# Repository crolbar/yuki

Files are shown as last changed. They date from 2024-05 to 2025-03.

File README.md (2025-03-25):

<h1 align="center">YUKI</h1>

<div align="center">
YUKI is a split diodless keyboard with a column stagger layout heavily inspired by <a href="https://github.com/diepala/cantor">cantor</a>.
</div>
<br/><br/>

YUKI
Made with [Keyberon](https://github.com/TeXitoi/keyberon)

<br/>

### Layers
| Layer | Description |
|---|---|
| [layer 0](http://www.keyboard-layout-editor.com/#/gists/67aaf9d778e9b2ddf6e25b263cbe5ed5) | Firmware Dvorak |
| [layer 1](http://www.keyboard-layout-editor.com/#/gists/5f7a4db98ea4d0b959304c4fe80d1d7f) | Numbers & Symbols |
| [layer 2](http://www.keyboard-layout-editor.com/#/gists/3af9d73abaec154f56b99b5a6c55cf5e) | Less used keys & Macros  |
| layer 3 | Mouse movement & buttons |
| layer 4 | Qwerty |

<br/>

### Features

- 44 keys, v0.1 - Cherry MX & v0.2 - Kailh Choc V1 switches
- Uses only 1U keycaps
- TRRS connection is used for communication between the two halves
- 2 USB-C connectors, with a choice from which the keyboard should send keystrokes
- Mouse control
- OLED display (not installed in the v0.2 picture)

<br/>

# Bill of Materials

| Product | Qty | Note |
|---|-----|---|
| YUKI PCB | 2 | [KiCad](https://kicad.org/) project files can be found in `yuki_pcb` directory. I ordered them from [JLCPCB](https://jlcpcb.com). They are reversible so you will use the same pcb for both left and right. |
| STM32F401CCU6 | 2 | Can be found on aliexpress. I have ordered mine from a local vendor. |
| TRRS jacks | 2 | `PJ-320A` |
| TRRS cable | 1 | 3.5mm jack cable, with 3 stripes. |
| Switches | 44  | Cherry MX for v0.1 and Kailh Choc V1 for v0.2. Ordered from [splitkb](https://splitkb.com/collections/switches-and-keycaps/products/kailh-low-profile-choc-switches) |
| Keycaps | 44  | 1U keycaps. Ordered from [splitkb](https://splitkb.com/collections/switches-and-keycaps/products/blank-mbk-choc-low-profile-keycaps). |

# Flashing the firmware

You will need rust installed so:
```
curl --proto '=https' --tlsv1.2 -sSf https://sh.rustup.rs | sh
```

cargo-binutils for stripping unused data from the rust binary and other optimizations:
```
rustup component add llvm-tools
cargo install cargo-binutils
```

dfu-util for flashing:
```
sudo pacman -S dfu-util
```

add the rust target for the MCU:
```
rustup target add thumbv7em-none-eabihf
```

then to compile the firmware:
``` 
cargo objcopy --bin yuki --release -- -O binary yuki.bin
```
for the right board add `--features right`

to flash enter dfu by holding BOOT clicking RESET and releasing BOOT and enter (can be tricky):
```
dfu-util -d 0483:df11 -a 0 --dfuse-address 0x08000000:leave -D yuki.bin"
```

After that to enter dfu just hold button 05 and 33 click reset and release the buttons.

### Nix

if you are on NixOS you could use the devShell:

enter the dev shell:
```
nix develop
```

and use the flash script that can be found in `flash.nix`
```
flash right
```

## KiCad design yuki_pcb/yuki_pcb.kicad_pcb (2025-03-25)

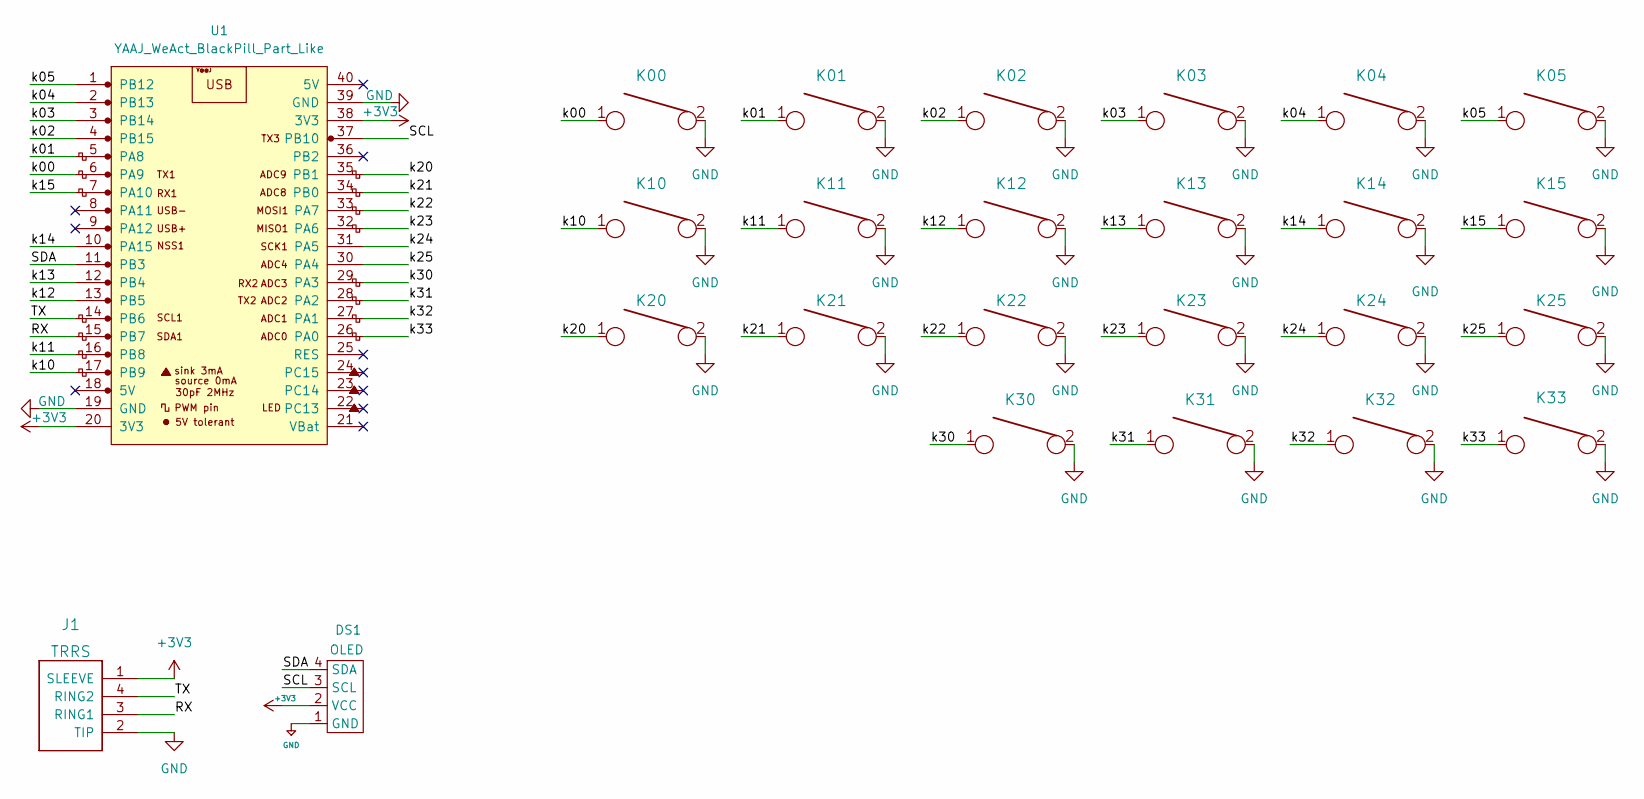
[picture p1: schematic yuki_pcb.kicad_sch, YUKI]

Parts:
DS1: OLED
J1: TRRS; MJ-4PP-9_Cantor_MX_TX-RX_Crossover
K00, K01, K02, K03, K04, K05, K10, K11, K12, K13, K14, K15, K20, K21, K22, K23, K24, K25, K30, K31, K32, K33: KEYSW; Kailh_Choc_PG1350_rev
U1: YAAJ_WeAct_BlackPill_Part_Like; YUKI_YAAJ_WeAct_BlackPill_2

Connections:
+3V3: DS1.2 (VCC), J1.1 (SLEEVE), U1.20 (3V3), U1.38 (3V3)
/RX: J1.3 (RING1), U1.15 (PB7)
/SCL: DS1.3 (SCL), U1.37 (PB10)
/SDA: DS1.4 (SDA), U1.11 (PB3)
/TX: J1.4 (RING2), U1.14 (PB6)
/k00: K00.1, U1.6 (PA9)
/k01: K01.1, U1.5 (PA8)
/k02: K02.1, U1.4 (PB15)
/k03: K03.1, U1.3 (PB14)
/k04: K04.1, U1.2 (PB13)
/k05: K05.1, U1.1 (PB12)
/k10: K10.1, U1.17 (PB9)
/k11: K11.1, U1.16 (PB8)
/k12: K12.1, U1.13 (PB5)
/k13: K13.1, U1.12 (PB4)
/k14: K14.1, U1.10 (PA15)
/k15: K15.1, U1.7 (PA10)
/k20: K20.1, U1.35 (PB1)
/k21: K21.1, U1.34 (PB0)
/k22: K22.1, U1.33 (PA7)
/k23: K23.1, U1.32 (PA6)
/k24: K24.1, U1.31 (PA5)
/k25: K25.1, U1.30 (PA4)
/k30: K30.1, U1.29 (PA3)
/k31: K31.1, U1.28 (PA2)
/k32: K32.1, U1.27 (PA1)
/k33: K33.1, U1.26 (PA0)
GND: DS1.1 (GND), J1.2 (TIP), K00.2, K01.2, K02.2, K03.2, K04.2, K05.2, K10.2, K11.2, K12.2, K13.2, K14.2, K15.2, K20.2, K21.2, K22.2, K23.2, K24.2, K25.2, K30.2, K31.2, K32.2, K33.2, U1.19 (GND), U1.39 (GND)

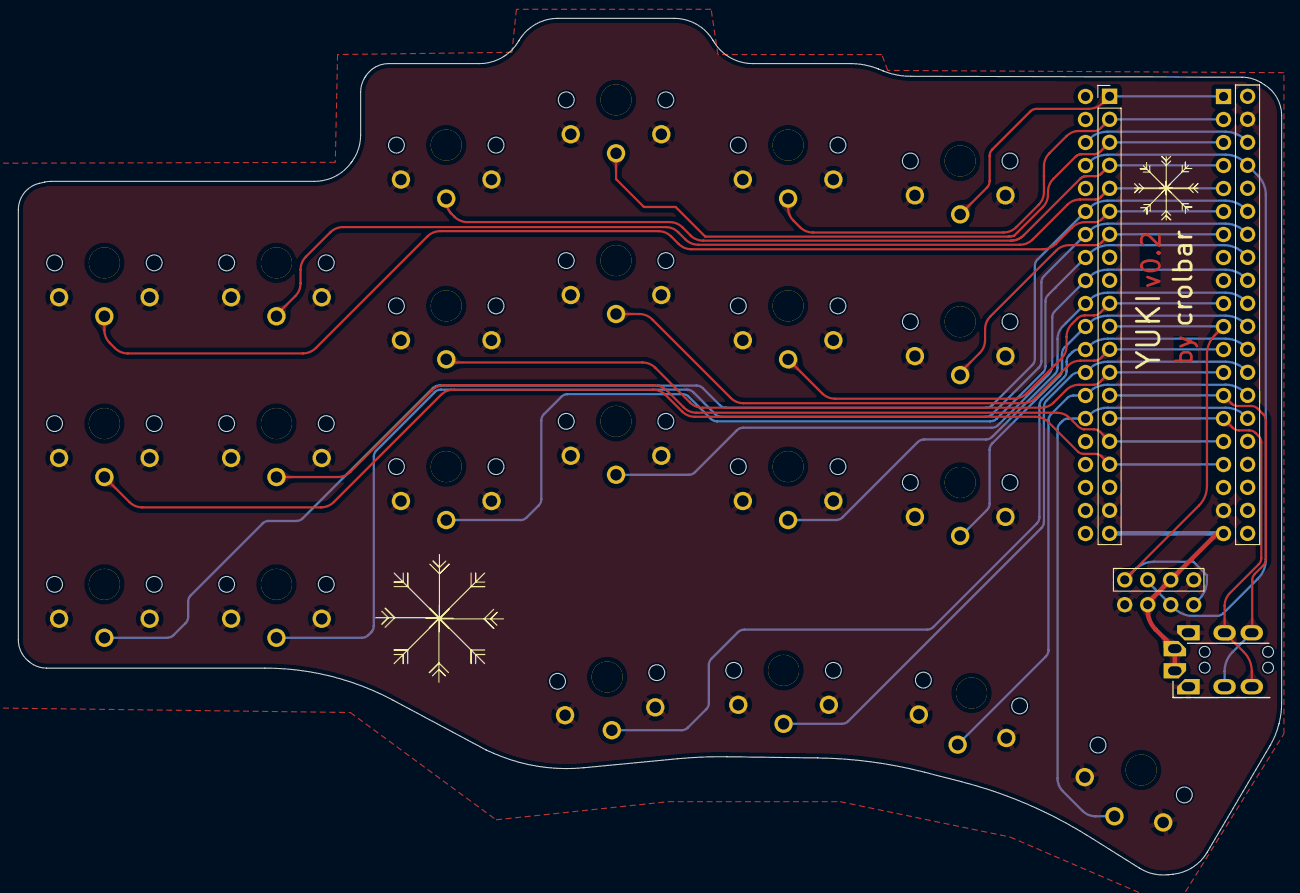
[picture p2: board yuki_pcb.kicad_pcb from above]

Board: 2 copper layers, 139.5 x 94.6 mm, 25 parts (0 on the bottom side), 28 nets.

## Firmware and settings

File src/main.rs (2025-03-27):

#![no_std]
#![no_main]

use panic_halt as _;
use stm32f4xx_hal as hal;
mod layout;
mod oled;
mod mouse;

#[rtic::app(device = hal::pac, dispatchers = [TIM1_CC])]
mod app {
    use {
        super::*,

        hal::{
            gpio::{EPin, Input, PC13, Output, PushPull},
            otg_fs::{UsbBus, UsbBusType, USB},
            pac::{USART1, TIM2},
            timer::counter::CounterHz,
            prelude::*,
            serial
        },
        cortex_m::interrupt,

        nb::block,

        usb_device::prelude::*,

        keyberon::{
            debounce::Debouncer,
            key_code::KbHidReport,
            layout::{Event, Layout, CustomEvent},
            matrix::DirectPinMatrix,
            keyboard
        },

        layout::{LAYERS, CustomAction},
        oled::OLED,
        mouse::Mouse,
    };


    const MANUFACTURER: &str = "crolbar";
    const PRODUCT: &str = "YUKI";
    const SERIAL_NUMBER: &str = "1337";

    const NUM_COLS: usize = 6;
    const NUM_ROWS: usize = 4;

    const NUM_LAYERS: usize = LAYERS.len();

    const USE_RIGHT_USB_INIT: bool = true;


    pub struct Leds { caps_lock:  PC13<Output<PushPull>> }

    impl keyboard::Leds for Leds {
        fn caps_lock(&mut self, status: bool) {
            match status {
                true => self.caps_lock.set_low(),
                false => self.caps_lock.set_high(),
            }
        }
    }

    #[shared]
    struct Shared {
        usb_dev: UsbDevice<'static, UsbBusType>,
        usb_class: keyberon::Class<'static, UsbBusType, Leds>,
        layout: Layout<{NUM_COLS*2}, NUM_ROWS, NUM_LAYERS, CustomAction>,
        mouse: Mouse
    }

    #[local]
    struct Local {
        matrix: DirectPinMatrix<EPin<Input>, NUM_COLS, NUM_ROWS>,
        debouncer: Debouncer<[[bool; NUM_COLS]; NUM_ROWS]>,
        timer: CounterHz<TIM2>,
        tx: serial::Tx<USART1>,
        rx: serial::Rx<USART1>,
        enter_dfu: bool,
        use_right_usb: bool,
        #[cfg(feature = "oled")]
        oled: OLED,
    }


    #[init(
        local = [
            bus: Option<usb_device::bus::UsbBusAllocator<UsbBusType>> = None,
            ep_memory: [u32; 1024] = [0; 1024]
        ]
    )]
    fn init(ctx: init::Context) -> (Shared, Local, init::Monotonics) {
        let mut clocks = ctx
            .device
            .RCC
            .constrain()
            .cfgr
            .use_hse(25.MHz())
            .sysclk(84.MHz())
            .require_pll48clk()
            .freeze();

        let gpioa = ctx.device.GPIOA.split();
        let gpiob = ctx.device.GPIOB.split();
        let gpioc = ctx.device.GPIOC.split();

        // easier dfu enter keys
        let pa0 = gpioa.pa0.into_pull_up_input();
        let pb12 = gpiob.pb12.into_pull_up_input();

        let mut timer = ctx.device.TIM2.counter_hz(&mut clocks);
        timer.start(1.kHz()).unwrap();
        timer.listen(hal::timer::Event::Update);


        let usb = USB::new(
            (
                ctx.device.OTG_FS_GLOBAL,
                ctx.device.OTG_FS_DEVICE,
                ctx.device.OTG_FS_PWRCLK,
            ), 
            (gpioa.pa11, gpioa.pa12), &clocks
        );


        let mut caps_lock = gpioc.pc13.into_push_pull_output();
        caps_lock.set_high();

        *ctx.local.bus = Some(UsbBus::new(usb, ctx.local.ep_memory));
        let usb_bus = ctx.local.bus.as_ref().unwrap();

        let usb_class = keyberon::new_class(usb_bus, Leds {caps_lock});

        let mouse = Mouse::new(usb_bus);

        let usb_dev = UsbDeviceBuilder::new(usb_bus, UsbVidPid(0x16c0, 0x27db))
        .strings(&[StringDescriptors::default()
            .manufacturer(MANUFACTURER)
            .product(PRODUCT)
            .serial_number(SERIAL_NUMBER)])
        .unwrap()
        .build();

        // easier dfu check if keys are pressed
        // do this a bit after setting the pins to high
        let enter_dfu = pa0.is_low() && pb12.is_low();

        let matrix = interrupt::free(move |_| {
            DirectPinMatrix::new([
                [
                    Some(gpioa.pa9.into_pull_up_input().erase()),
                    Some(gpioa.pa8.into_pull_up_input().erase()),
                    Some(gpiob.pb15.into_pull_up_input().erase()),
                    Some(gpiob.pb14.into_pull_up_input().erase()),
                    Some(gpiob.pb13.into_pull_up_input().erase()),
                    Some(pb12.into_pull_up_input().erase()),
                ],
                [
                    Some(gpiob.pb9.into_pull_up_input().erase()),
                    Some(gpiob.pb8.into_pull_up_input().erase()),
                    Some(gpiob.pb5.into_pull_up_input().erase()),
                    Some(gpiob.pb4.into_pull_up_input().erase()),
                    Some(gpioa.pa15.into_pull_up_input().erase()),
                    Some(gpioa.pa10.into_pull_up_input().erase()),
                ],
                [
                    Some(gpiob.pb1.into_pull_up_input().erase()),
                    Some(gpiob.pb0.into_pull_up_input().erase()),
                    Some(gpioa.pa7.into_pull_up_input().erase()),
                    Some(gpioa.pa6.into_pull_up_input().erase()),
                    Some(gpioa.pa5.into_pull_up_input().erase()),
                    Some(gpioa.pa4.into_pull_up_input().erase()),
                ],
                [
                    None,
                    None,
                    Some(gpioa.pa3.into_pull_up_input().erase()),
                    Some(gpioa.pa2.into_pull_up_input().erase()),
                    Some(gpioa.pa1.into_pull_up_input().erase()),
                    Some(pa0.into_pull_up_input().erase()),
                ],
            ]).unwrap()
        });

        let mut serial = serial::Serial::new(
            ctx.device.USART1,
            interrupt::free(move |_| 
                (gpiob.pb6.into_alternate::<7>(), gpiob.pb7.into_alternate::<7>())
            ),
            38_400.bps(),
            &mut clocks
        ).unwrap().with_u8_data();

        serial.listen(serial::Event::RxNotEmpty);
        let (tx, rx) = serial.split();

        (
            Shared {
                usb_dev,
                usb_class,
                layout: Layout::new(&LAYERS),
                mouse,
            },
            Local {
                matrix,
                timer,
                debouncer: Debouncer::new(
                    [[false; NUM_COLS]; NUM_ROWS],
                    [[false; NUM_COLS]; NUM_ROWS],
                    NUM_LAYERS.try_into().unwrap()
                ),
                tx, rx,
                enter_dfu,
                use_right_usb: USE_RIGHT_USB_INIT,
                #[cfg(feature = "oled")]
                oled: OLED::new(
                    gpiob.pb10.into_alternate().set_open_drain(),
                    gpiob.pb3.into_alternate().set_open_drain(),
                    ctx.device.I2C2, &clocks
                )
            },
            init::Monotonics(),
       )
    }

    #[task(priority = 3, capacity = 8, shared = [layout])]
    fn handle_event(mut ctx: handle_event::Context, event: Event) {
        ctx.shared.layout.lock(|l| l.event(event))
    }

    #[task(binds = USART1, priority = 2, local = [rx])]
    fn rx(ctx: rx::Context) {
        if let Ok(b) = ctx.local.rx.read() {
            if let Ok(event) = de(b) {
                #[cfg(not(feature = "right"))]
                let event = event.transform(|i, j| (i, 11 - j));

                handle_event::spawn(event).unwrap();
            }
        }
    }

    #[task(
        binds=TIM2,
        priority=1,
        local=[debouncer, matrix, timer, tx, oled, use_right_usb],
        shared=[usb_dev, usb_class, layout, mouse]
    )]
    fn tick(mut ctx: tick::Context) {
        ctx.local.timer.wait().ok();

        ctx.local
            .debouncer
            .events(ctx.local.matrix.get().unwrap())
            .for_each(|e| {
                block!(ctx.local.tx.write(ser(e))).unwrap();

                #[cfg(feature = "right")]
                let e = e.transform(|i, j| (i, 11 - j));

                handle_event::spawn(e).unwrap();
            });

        ctx.shared.mouse.lock(|m| m.mouse_tick());
        match ctx.shared.layout.lock(|l| l.tick()) {
            CustomEvent::NoEvent => (),
            CustomEvent::Press(CustomAction::USB) => *ctx.local.use_right_usb = !*ctx.local.use_right_usb,
            CustomEvent::Press(CustomAction::M(maction)) => ctx.shared.mouse.lock(|m| m.handle_mouse_btn(maction, true)),
            CustomEvent::Release(CustomAction::M(maction)) => ctx.shared.mouse.lock(|m| m.handle_mouse_btn(maction, false)),
            _ => ()
        }

        let use_right_usb = ctx.local.use_right_usb;

        if ctx.shared.usb_dev.lock(|d| d.state()) == UsbDeviceState::Configured {
            #[cfg(feature = "right")] let cond = *use_right_usb;
            #[cfg(not(feature = "right"))] let cond = !*use_right_usb;

            if cond {
                let report: KbHidReport = ctx.shared.layout.lock(|l| l.keycodes().collect());
                if ctx.shared.usb_class.lock(|k| k.device_mut().set_keyboard_report(report.clone())) {
                    while let Ok(0) = ctx.shared.usb_class.lock(|k| k.write(report.as_bytes())) {}
                }

                while let Ok(()) = ctx.shared.mouse.lock(|m| m.mouse.device().write_report(&m.report)) {}
            }
        }

        #[cfg(feature = "oled")]
        ctx.local.oled.draw(
            ctx.shared.layout.lock(|l| l.current_layer()),
            *use_right_usb
        )
    }

    #[idle(local = [enter_dfu])]
    fn idle(ctx: idle::Context) -> ! {
        // if pa0 && pb12 are shorted and the board resets this will load dfu
        if *ctx.local.enter_dfu {
            unsafe { cortex_m::asm::bootload(0x1FFF0000 as _) }
        }

        loop { rtic::export::wfi() }
    }

    // im using one byte for the coords and the is_press status
    // the last three bits are the y
    // the second to last three are the x
    // the first bit is the is_press status
    //                                     press     5       2
    // so for example Event::Press(2, 5) == (1) 0 (1 0 1) (0 1 0)
    //
    // this only works with 8 or less columns or rows
    fn ser(e: Event) -> u8 {
        let (y, x) = e.coord();
        y | x << 3 | (e.is_press() as u8) << 7
    }
    fn de(n: u8) -> Result<Event, ()> {
        match n & 128 {
            128 => Ok(Event::Press(n & 7, (n & 56) >> 3)),
            0 => Ok(Event::Release(n & 7, (n & 56) >> 3)),
            _ => Err(())
        } 
    }

    use usb_device::class::UsbClass;
    #[task(binds = OTG_FS, priority = 3, shared = [usb_dev, usb_class, mouse])]
    fn usb(ctx: usb::Context) {
        (ctx.shared.usb_dev, ctx.shared.usb_class, ctx.shared.mouse)
        .lock(|usb_dev, kb, m| {
            if m.active {
                if usb_dev.poll(&mut [&mut m.mouse, kb]) { kb.poll() }
            } else {
                if usb_dev.poll(&mut [kb]) { kb.poll() }
            }
        });
    }
}

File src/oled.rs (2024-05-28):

use stm32f4xx_hal as hal;

use {
    embedded_graphics::{
        mono_font::{iso_8859_16::FONT_10X20 as FONT, MonoTextStyleBuilder, MonoTextStyle},
        pixelcolor::BinaryColor,
        prelude::*,
        image::{Image, ImageRaw},
        text::{Baseline, Text},
    },
    hal::{
        prelude::*,
        i2c::{Mode, I2c},
        pac::I2C2,
        gpio
    },
    ufmt::uwrite,

    ssd1306::{mode::BufferedGraphicsMode, prelude::*, Ssd1306}
};

pub type Display = Ssd1306<I2CInterface<I2c<I2C2>>, DisplaySize128x32, BufferedGraphicsMode<DisplaySize128x32>>;

const TEXT_STYLE: MonoTextStyle<BinaryColor> = MonoTextStyleBuilder::new()
    .font(&FONT)
    .text_color(BinaryColor::On)
    .build();

#[allow(dead_code)]
pub struct OLED {
    display: Display,
    prev_layer: usize,
    prev_uru: bool,
}

#[allow(dead_code)]
impl OLED {
    pub fn new(
        scl: gpio::gpiob::PB10<gpio::Alternate<4, gpio::OpenDrain>>,
        sda: gpio::gpiob::PB3<gpio::Alternate<9, hal::gpio::OpenDrain>>,
        i2c2: I2C2,
        clocks: &hal::rcc::Clocks
    ) -> Self {
        let mut display = Ssd1306::new(
            ssd1306::I2CDisplayInterface::new(
                I2c::new(
                    i2c2,
                    (scl, sda),
                    Mode::fast(
                        400.kHz(),
                        hal::i2c::DutyCycle::Ratio2to1
                    ),
                    &clocks
                )
            ),
            DisplaySize128x32,
            DisplayRotation::Rotate90,
        ).into_buffered_graphics_mode();
        display.init().unwrap();

        Self {
            display,
            prev_layer: 0,
            prev_uru: false,
        }
    }

    pub fn draw(&mut self, curr_layer: usize, uru: bool) {
        if 
            curr_layer != self.prev_layer ||
            uru != self.prev_uru
        {
            self.prev_layer = curr_layer;
            self.prev_uru = uru;

            let display = &mut self.display;
            let mut txt: heapless::String<32> = heapless::String::new();


            {
                let img: ImageRaw<BinaryColor> = ImageRaw::new(include_bytes!("../img.raw"), 32);
                Image::new(&img, Point::new(0, 0)).draw(display).unwrap();
            }

            {
                let _ = uwrite!(&mut txt, "L {}", curr_layer);

                Text::with_baseline(
                    &txt,
                    Point::new(2, 55),
                    TEXT_STYLE,
                    Baseline::Top
                ).draw(display).unwrap();
            }

            {
                txt.clear(); 
                let _ = uwrite!(&mut txt, "{}", 
                    if uru { "-->" } else { "<--" }
                );

                Text::with_baseline(&txt,
                    Point::new(2, 100),
                    TEXT_STYLE,
                    Baseline::Top
                ).draw(display).unwrap();
            }

            display.flush().unwrap();
        }
    }
}

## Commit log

2024-04-07 rounded edges
    [bom.csv, designators.csv, positions.csv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]
2024-04-07 more silksreen
    [bom.csv, designators.csv, positions.csv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]
2024-04-21 some firmware
    [yuki_pcb.kicad_pcb]
2024-04-25 capslock led
2024-04-29 add button to change which board sends keyboard reports
2024-04-30 fix crash when trying to write kb_report when usb not connected
    [main.rs]
2024-05-05 add layer 2 as condition on usb switcher
2024-05-28 fix: windows no likey mouse in the keyboard
    [main.rs]
2024-06-27 swap alt and ctrl && more media buttons
2025-03-25 v0.2 with Choc switches!
    [yuki_pcb.kicad_pcb, yuki_pcb.kicad_sch, yuki_pcb_V01.kicad_pcb]
2025-03-27 fix: dfu on keyboard plug in. (check for dfu enter a bit later)
    [main.rs]
